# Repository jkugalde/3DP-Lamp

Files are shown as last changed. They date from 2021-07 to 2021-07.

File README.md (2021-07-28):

# 3DP Lamp

[][cc-by-sa]

I made a lamp to work in my 3030 T-SLot table, this is the second version.

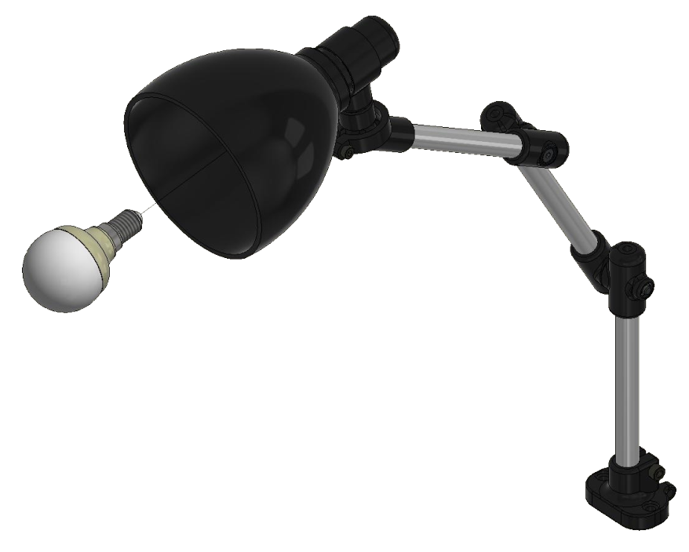
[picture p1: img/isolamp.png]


## Features

- Cheap
- Rotation at the base, two hinge joints and a spherical joint at the top.
- The cable goes inside the tubes.
- Base must be bolted to the table, with M5 bolts... or you can use screws.

## How to build it

- [LIST](parts.md) of parts, pieces and tools. 
- [CAD files](parts/).
- [Assembly instructions](assembly.md)

## Future work

- Assembly guide with images.

# License

[][cc-by-sa]

This work is published under the license [Creative Commons Attribution 4.0 International
License][cc-by-sa].

[cc-by-sa]: https://creativecommons.org/licenses/by-sa/4.0/
[cc-by-sa-image]: https://i.creativecommons.org/l/by-sa/4.0/88x31.png
[cc-by-sa-shield]: https://img.shields.io/badge/License-CC%20BY%20SA%204.0-lightgrey.svg

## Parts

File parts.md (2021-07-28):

# Parts

## Commercial parts

 ITEM              | QTY
 ---------------------------   | ------------
 Led Bulb E14 | 1
 Socket E14 | 1
 12.6 mm aluminium tube | 1 m
 M5x45 bolt | 2
 M5x20 bolt | 2
 M5 nut | 1
 M5 lock nut | 3
 M5 washer | 2
 M4x20 bolt | 1
 M4 nut | 1

 Note: You also need to make an interruptor circuit, with some wires, an electrical plug and a switch.

## Printed parts

You can find the .step and .stl files in the [parts folder](parts/). 

 ITEM                   | Cantidad
 ---------------------------   | ------------
 Screen | 1
 Socket holder | 1
 Ball joint | 1
 Ball connector | 1
 Ball lock | 1
 Connector A | 2
 Connector B | 2
 Base | 1
 
## Tools

 ITEM |                  
 --------------------------- |  
 Saw or tube cutter |
 4 mm allen wrench | 
 3 mm allen wrench |

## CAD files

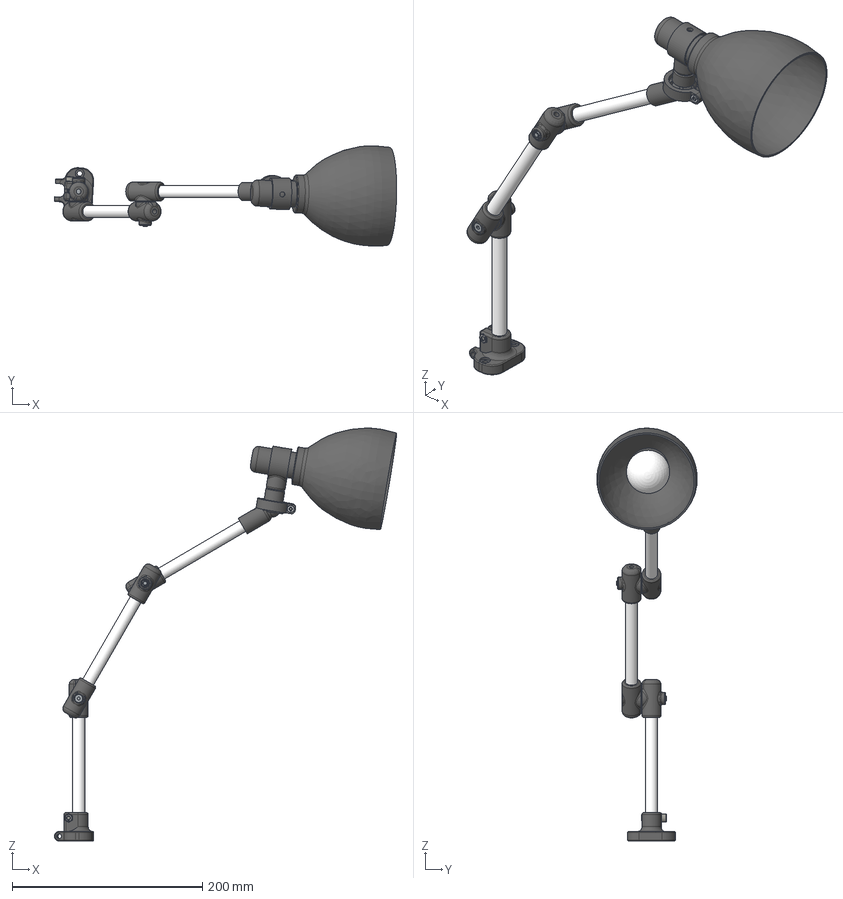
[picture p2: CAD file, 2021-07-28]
parts/Lamp.stp
360.3 x 105.7 x 434.7 mm
AlumTube x 3
Ballholder
BallJoint
LightHolder
Screen
LED Bulb
E14 socket
BallLock
M4Nut
M4x20
ConnectorA x 2
ConnectorB x 2
M5 washer x 2
M5 Lock nut x 3
Perno M5x8 cabeza plana x 2
LampBase
M5x20Bolt x 2
M5Nut

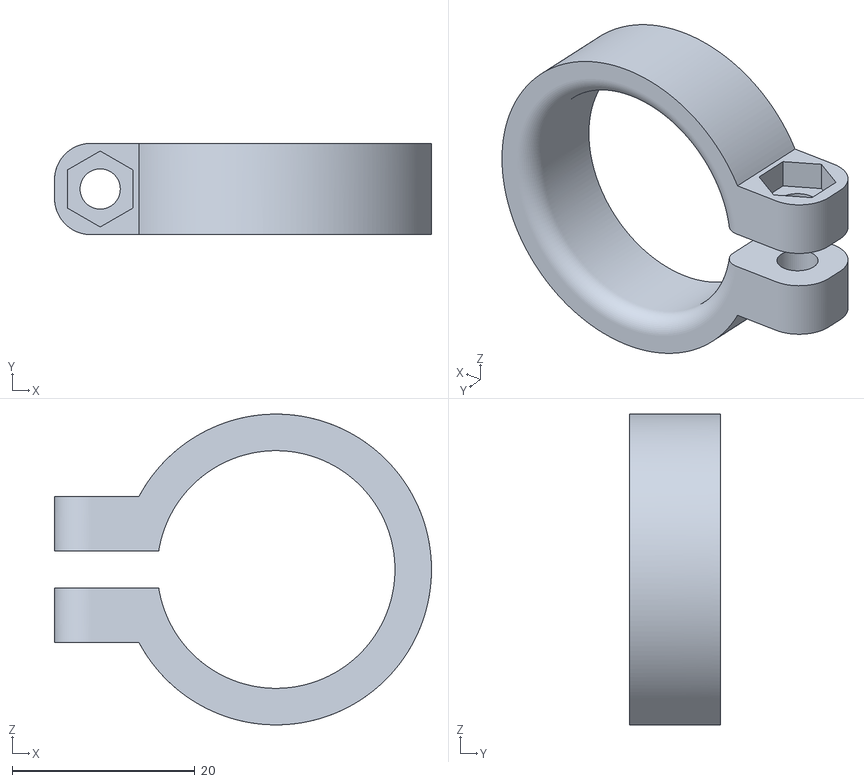
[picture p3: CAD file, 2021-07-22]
parts/STLs/BallLock.stl
41.2 x 10.0 x 34.0

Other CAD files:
parts/Inventor parts/Aluminium tube.ipt
parts/Inventor parts/BallConnector.ipt
parts/Inventor parts/BallJoint.ipt
parts/Inventor parts/BallLock.ipt
parts/Inventor parts/Base.ipt
parts/Inventor parts/ConnectorA.ipt
parts/Inventor parts/ConnectorB.ipt
parts/Inventor parts/ConnectorC.ipt
parts/Inventor parts/E14 socket.ipt
parts/Inventor parts/LED Bulb.ipt
parts/Inventor parts/Lamp.iam
parts/Inventor parts/M4 Nut.ipt
parts/Inventor parts/M4x20.ipt
parts/Inventor parts/M5 Lock nut.ipt
parts/Inventor parts/M5 Nut.ipt
parts/Inventor parts/M5 washer.ipt
parts/Inventor parts/M5x20.ipt
parts/Inventor parts/M5x45.ipt
parts/Inventor parts/Screen.ipt
parts/Inventor parts/SocketHolder.ipt

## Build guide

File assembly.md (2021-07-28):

# Asssembly guide

## Preparing parts

-Cut three pieces of the aluminium tube using a saw or tube cutter. They do not have to be necessarily the same size, 20 cm is ok for each piece.

## Step by step

- Put one piece of the aluminium tube inside the Base piece, and pass the wire through the back of it and into the tube until it comes out from the other side.
- Put a ConnectorA on top of the tube and pass the cables.
- Get another piece of aluminium tube an put a ConnectorB in it.
- Join the connectors with a M5x45 bolt, a washer in between the flat faces and with a lock nut on the other side.
- Pass the cable from the ConnectorA into the B and push them out of the second tube.
- Repeat the last two steps with the third aluminium piece.
- Pass the cable trough the BallConector and put it on top of the the aluminium tube.

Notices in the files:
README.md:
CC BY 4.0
